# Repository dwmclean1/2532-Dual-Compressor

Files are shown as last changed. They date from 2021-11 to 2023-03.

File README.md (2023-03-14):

# 2532-Dual-Compressor

## What is it?  

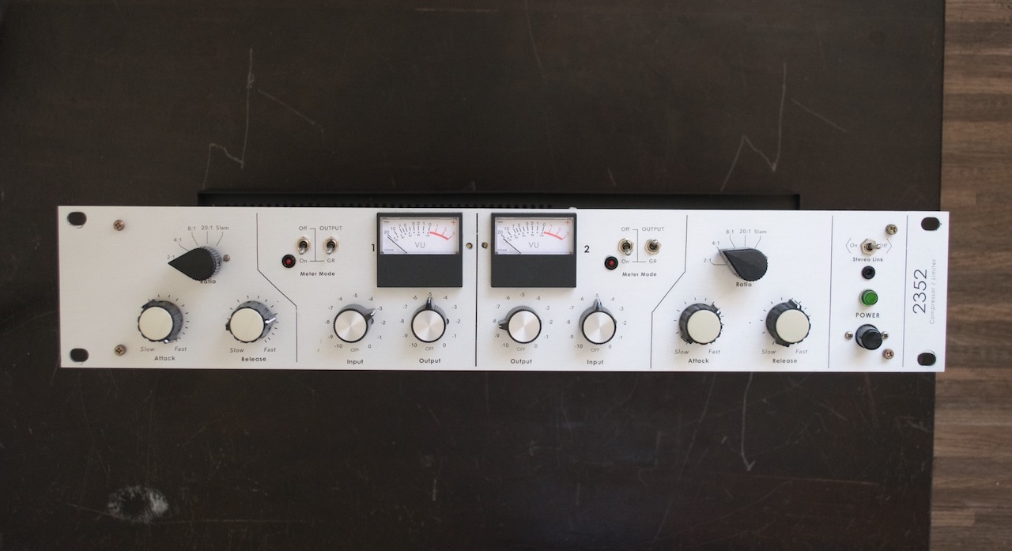
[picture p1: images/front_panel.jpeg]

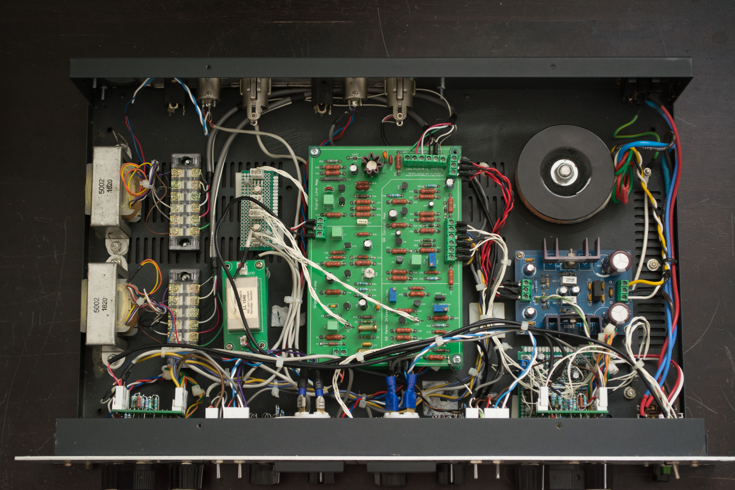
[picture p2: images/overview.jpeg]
  
  
This is a dual mono clone of the Urei 1176LN compressor (2 x 1176 = 2532). The main board is a direct copy of the original unit from the original schematic. The ratio board is taken from the mnats version [seen here](http://mnats.net/1176_revision_d.html).  
  
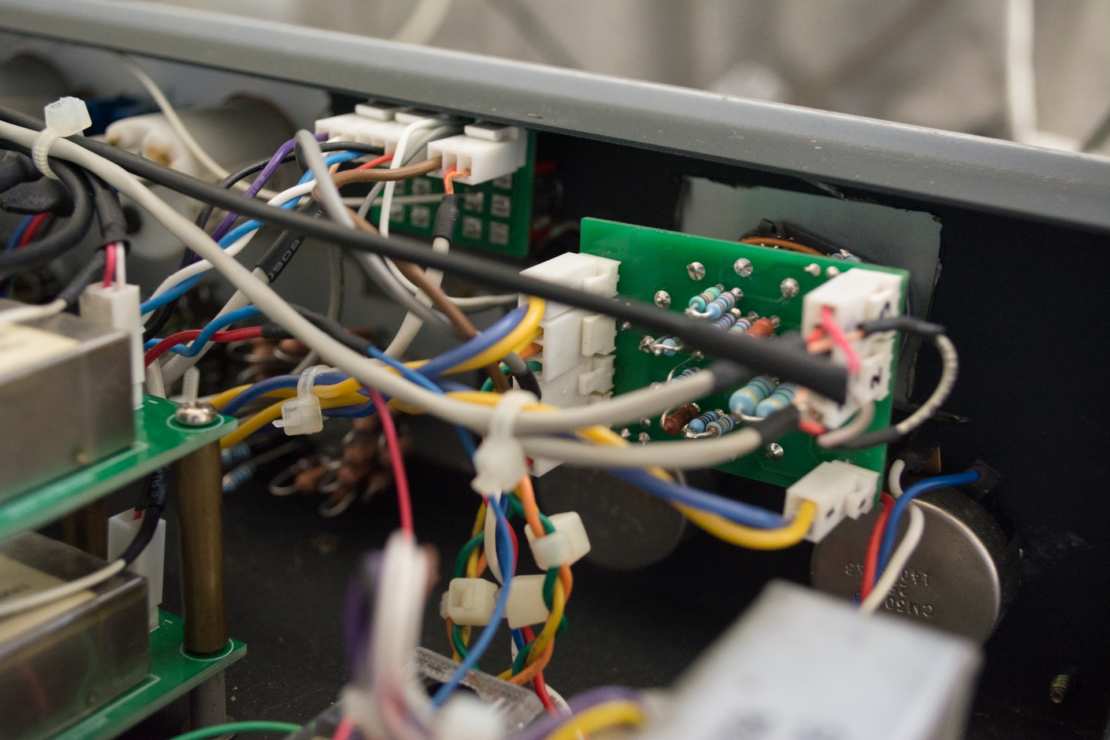
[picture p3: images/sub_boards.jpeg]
  

The meter mode board was designed by me and uses two DPDT toggle switches, one to chose between displaying output level or gain reduction level and one to bypass the compression path. The Stereo Link board is also based on the mnats version which you would usually required two of but to save space and wiring I combined them into one board. All the boards were designed in EagleCAD.  
  
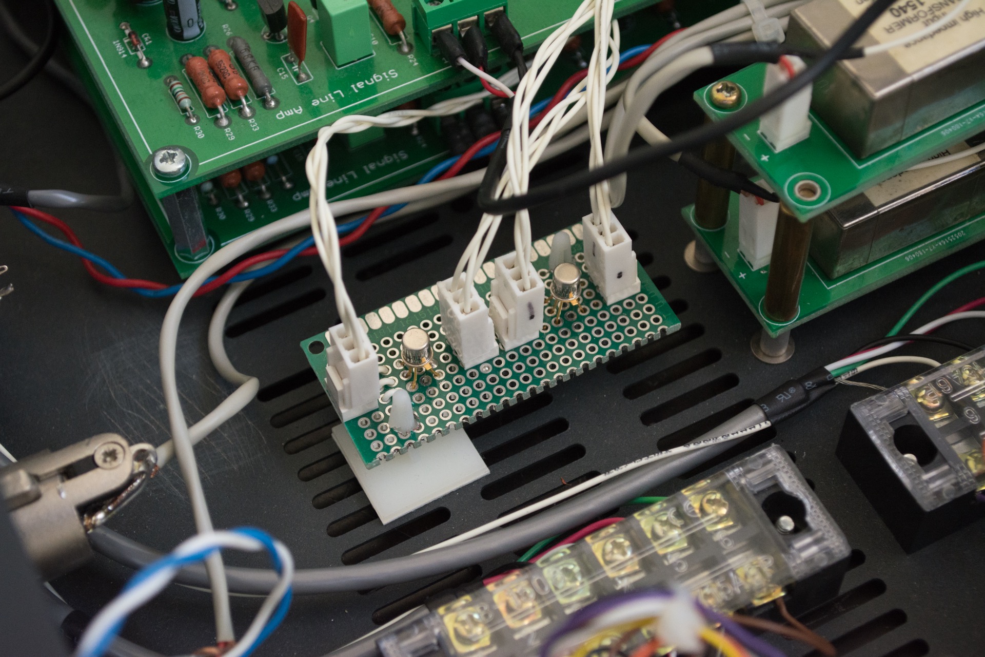
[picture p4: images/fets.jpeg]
  

The original 1176 used two BF245 JFETs, one for the compression path and one for the gain reduction meter. These would need to matched so that the gain reduction shown on the meter is accurate to the actual gain reduction applied to the audio signal. Instead of doing that I decided to use the Interfet INF411 which is a matched pair of JFETs in a simgle package and has similar characteristics to the BF245.

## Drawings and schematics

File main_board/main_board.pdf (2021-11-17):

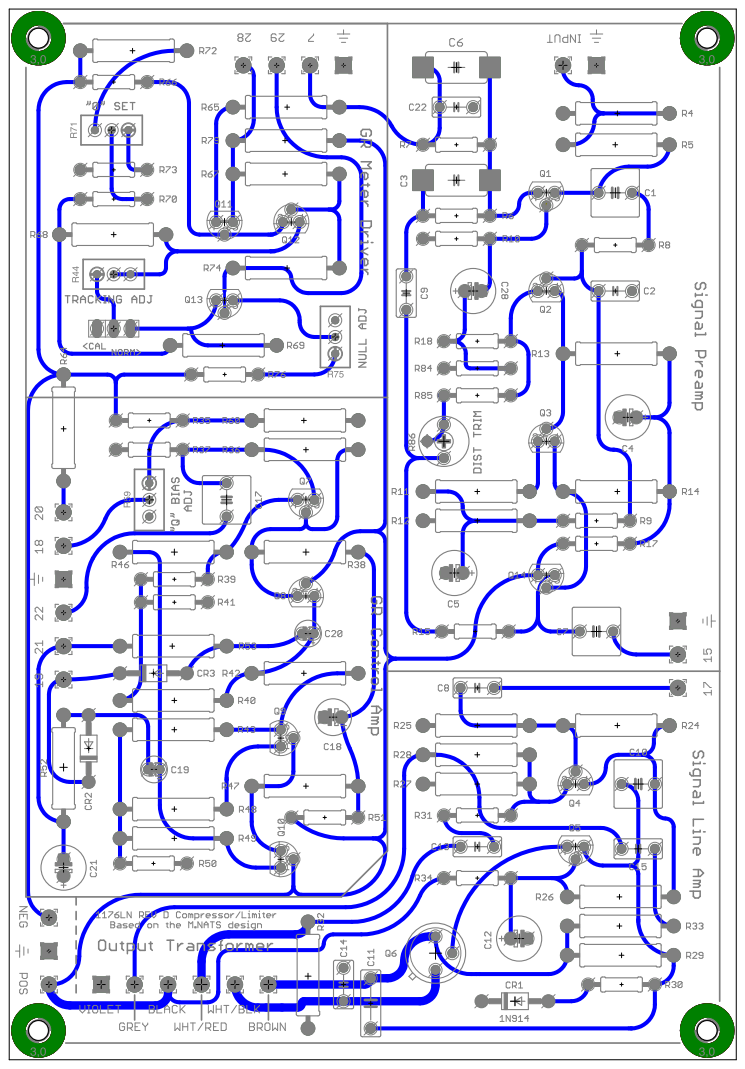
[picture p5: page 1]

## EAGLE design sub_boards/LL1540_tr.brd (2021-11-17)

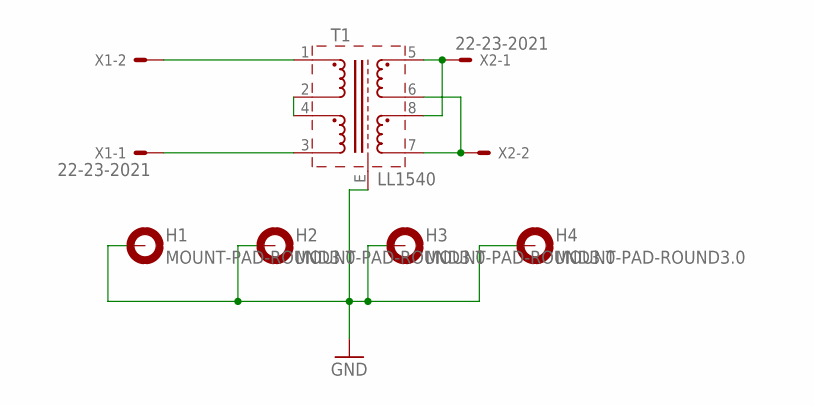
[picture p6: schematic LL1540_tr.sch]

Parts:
H1, H2, H3, H4: MOUNT-PAD-ROUND3.0; 3,0-PAD
T1: LL1540
X1, X2: 22-23-2021

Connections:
GND: H1.B3,0, H2.B3,0, H3.B3,0, H4.B3,0, T1.E
unnamed: T1.2, T1.4
unnamed: T1.1, X1.2
unnamed: T1.3, X1.1
unnamed: T1.5, T1.8, X2.1
unnamed: T1.6, T1.7, X2.2

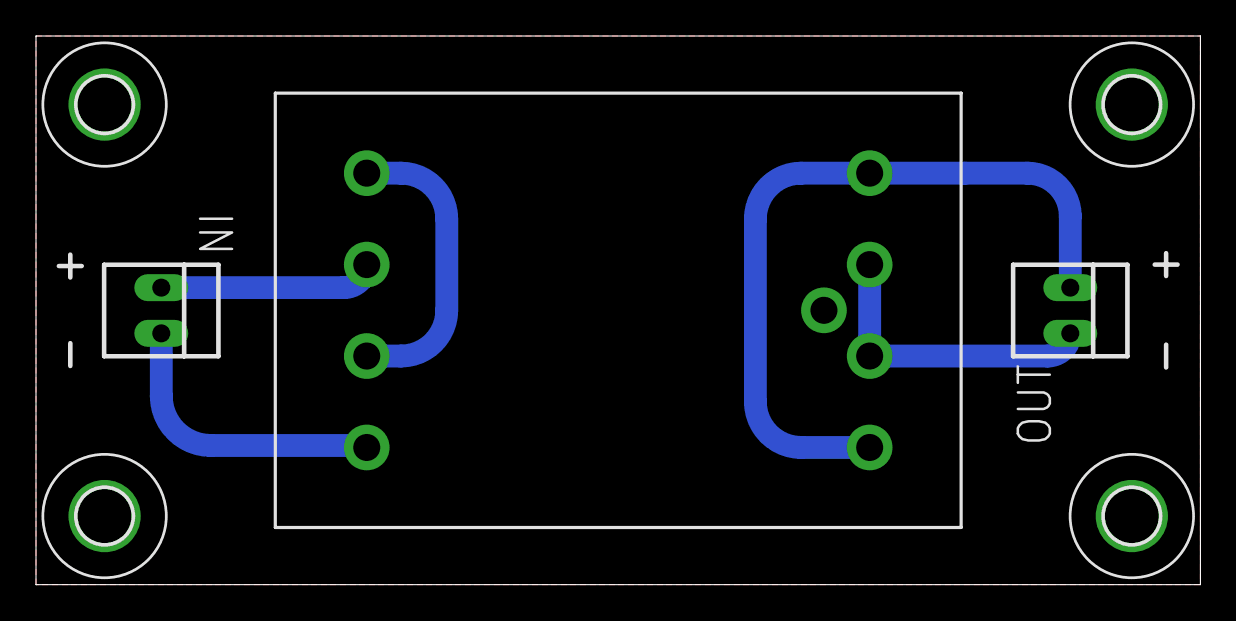
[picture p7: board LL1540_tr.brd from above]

Board: 2 copper layers, 64.7 x 30.5 mm, 7 parts (0 on the bottom side), 6 nets.

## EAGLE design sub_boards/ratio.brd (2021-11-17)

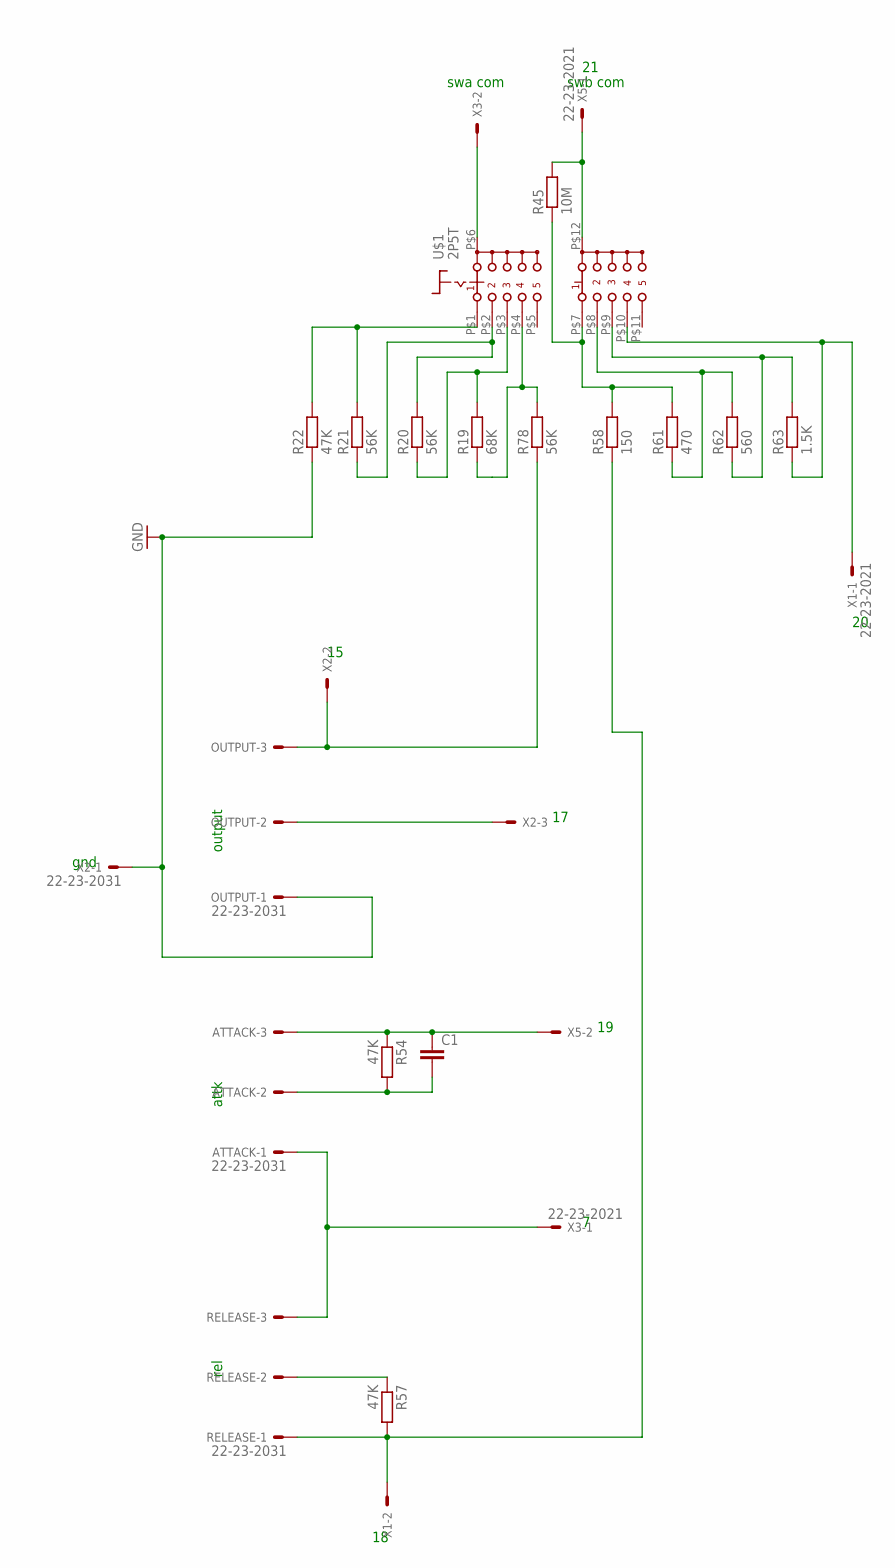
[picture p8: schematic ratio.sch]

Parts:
ATTACK: 22-23-2031
C1: C-EU025-025X050; C025-025X050
OUTPUT: 22-23-2031
R19: 68K; 0204V
R20, R21, R78: 56K; 0204V
R22, R54, R57: 47K; 0204V
R45: 10M; 0204V
R58: 150; 0204V
R61: 470; 0204V
R62: 560; 0204V
R63: 1.5K; 0204V
RELEASE: 22-23-2031
U$1: 2P5T
X1, X3, X5: 22-23-2021
X2: 22-23-2031

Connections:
GND: OUTPUT.1, R22.1, X2.1
unnamed: U$1.P$6 (A), X3.2
unnamed: R45.2, U$1.P$12 (C), X5.1
unnamed: R21.2, R22.2, U$1.P$1 (A1)
unnamed: R20.2, R21.1, U$1.P$2 (A2)
unnamed: R19.2, R20.1, U$1.P$3 (A3)
unnamed: R19.1, R78.2, U$1.P$4 (A4)
unnamed: OUTPUT.3, R78.1, X2.2
unnamed: R45.1, R58.2, R61.2, U$1.P$7 (C1)
unnamed: OUTPUT.2, X2.3
unnamed: ATTACK.3, C1.1, R54.1, X5.2
unnamed: R61.1, R62.2, U$1.P$8 (C2)
unnamed: R62.1, R63.2, U$1.P$9 (C3)
unnamed: R63.1, U$1.P$10 (C4), X1.1
unnamed: ATTACK.2, C1.2, R54.2
unnamed: ATTACK.1, RELEASE.3, X3.1
unnamed: R57.1, RELEASE.2
unnamed: R57.2, R58.1, RELEASE.1, X1.2

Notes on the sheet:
swa com
swb com
gnd
attk
rel
output

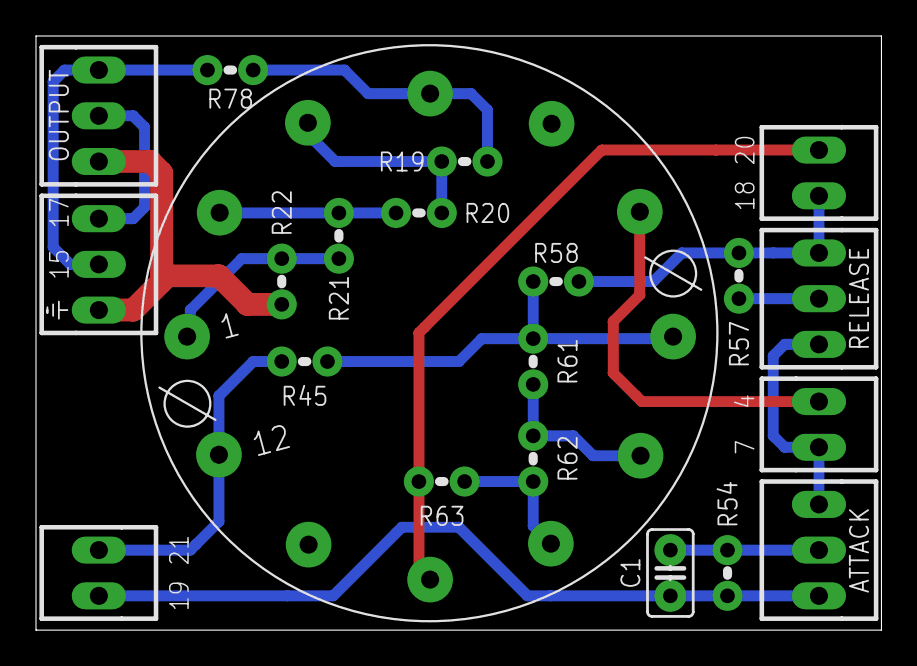
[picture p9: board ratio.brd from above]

Board: 2 copper layers, 47.0 x 33.0 mm, 21 parts (0 on the bottom side), 18 nets.

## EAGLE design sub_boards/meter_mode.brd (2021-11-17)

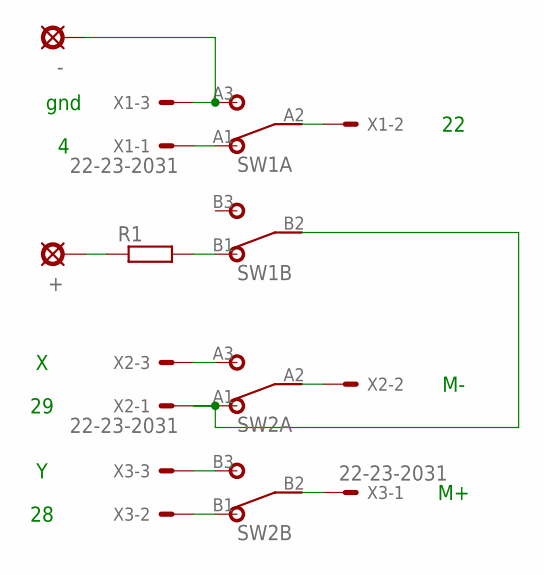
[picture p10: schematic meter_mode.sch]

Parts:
+: PADO; ROUND
-: PAD; SQUARE
R1: R-EU_0204/2V; 0204V
SW1, SW2: DPDT
X1, X2, X3: 22-23-2031

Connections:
unnamed: SW2.A3 (3), X2.3
unnamed: SW1.B2 (2), SW2.A1 (1), X2.1
unnamed: SW1.A1 (1), X1.1
unnamed: SW2.B3 (3), X3.3
unnamed: SW2.B1 (1), X3.2
unnamed: SW2.B2 (2), X3.1
unnamed: SW2.A2 (2), X2.2
unnamed: SW1.A2 (2), X1.2
unnamed: R1.2, SW1.B1 (1)
unnamed: -.1, SW1.A3 (3), X1.3
unnamed: +.1, R1.1

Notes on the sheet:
gnd

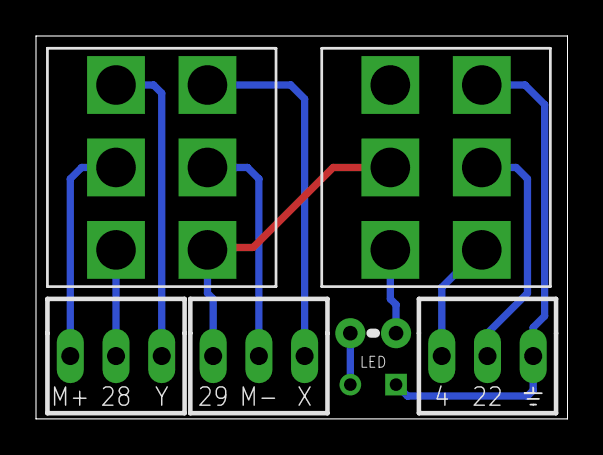
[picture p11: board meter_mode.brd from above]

Board: 2 copper layers, 29.5 x 21.3 mm, 8 parts (0 on the bottom side), 11 nets.

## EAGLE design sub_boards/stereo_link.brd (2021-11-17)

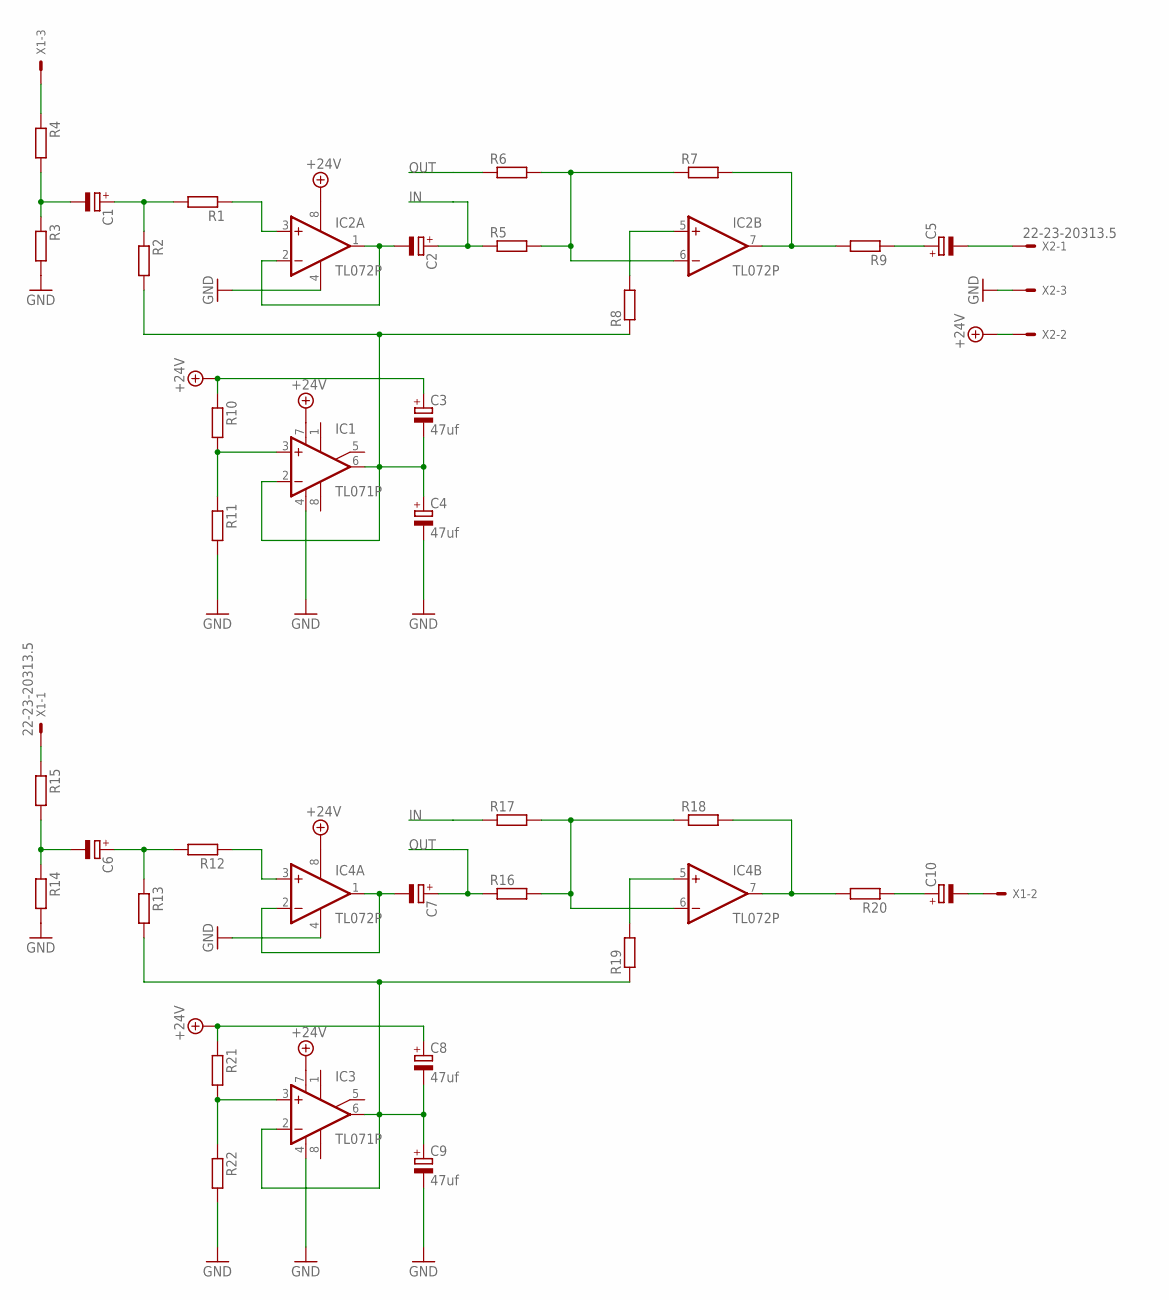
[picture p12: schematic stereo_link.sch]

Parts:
C1, C2, C5, C6, C7, C10: CPOL-EUE1.8-4; E1,8-4
C3, C4, C8, C9: 47uf; E2,5-6E
IC1, IC3: TL071P; DIL08
IC2, IC4: TL072P; DIL08
R1, R2, R3, R4, R5, R6, R7, R8, R9, R10, R11, R12, R13, R14, R15, R16, R17, R18, R19, R20, R21, R22: R-EU_0204/7; 0204/7
X1, X2: 22-23-20313.5; 3.5MM

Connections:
+24V: C3.+, C8.+, IC1.7 (V+), IC2.8 (V+), IC3.7 (V+), IC4.8 (V+), R10.1, R21.1, X2.P$2
GND: C4.-, C9.-, IC1.4 (V-), IC2.4 (V-), IC3.4 (V-), IC4.4 (V-), R3.2, R11.2, R14.2, R22.2, X2.P$3
unnamed: C1.-, R3.1, R4.2
unnamed: C1.+, R1.2, R2.1
unnamed: C6.-, R14.1, R15.2
unnamed: IC2.3 (+IN), R1.1
unnamed: C2.-, IC2.1 (OUT), IC2.2 (-IN)
unnamed: R15.1, X1.P$1
unnamed: C7.+, R6.1, R16.1
unnamed: IC2.6 (-IN), R5.2, R6.2, R7.1
unnamed: IC2.5 (+IN), R8.2
unnamed: IC2.7 (OUT), R7.2, R9.2
unnamed: C5.+, R9.1
unnamed: C5.-, X2.P$1
unnamed: IC1.3 (+IN), R10.2, R11.1
unnamed: C10.-, X1.P$2
unnamed: C6.+, R12.2, R13.1
unnamed: IC4.3 (+IN), R12.1
unnamed: C3.-, C4.+, IC1.2 (-IN), IC1.6 (OUT), R2.2, R8.1
unnamed: C7.-, IC4.1 (OUT), IC4.2 (-IN)
unnamed: R4.1, X1.P$3
unnamed: C2.+, R5.1, R17.1
unnamed: IC4.6 (-IN), R16.2, R17.2, R18.1
unnamed: IC4.5 (+IN), R19.2
unnamed: IC4.7 (OUT), R18.2, R20.2
unnamed: C10.+, R20.1
unnamed: IC3.3 (+IN), R21.2, R22.1
unnamed: C8.-, C9.+, IC3.2 (-IN), IC3.6 (OUT), R13.2, R19.1

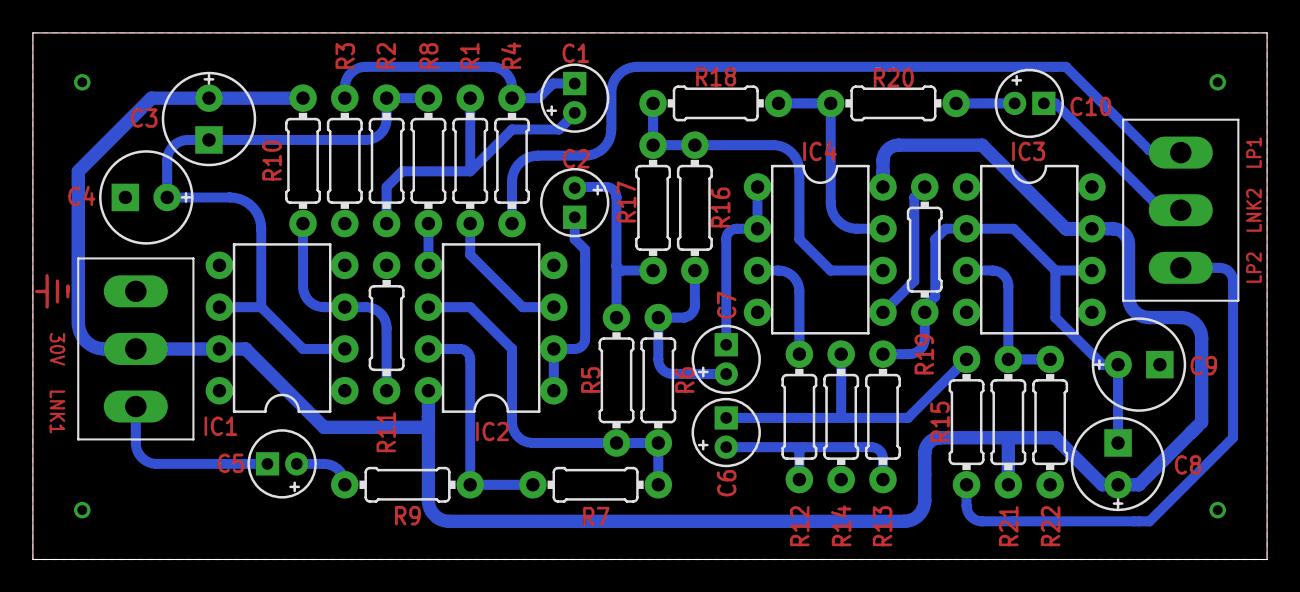
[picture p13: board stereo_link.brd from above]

Board: 2 copper layers, 75.0 x 32.0 mm, 38 parts (0 on the bottom side), 28 nets.

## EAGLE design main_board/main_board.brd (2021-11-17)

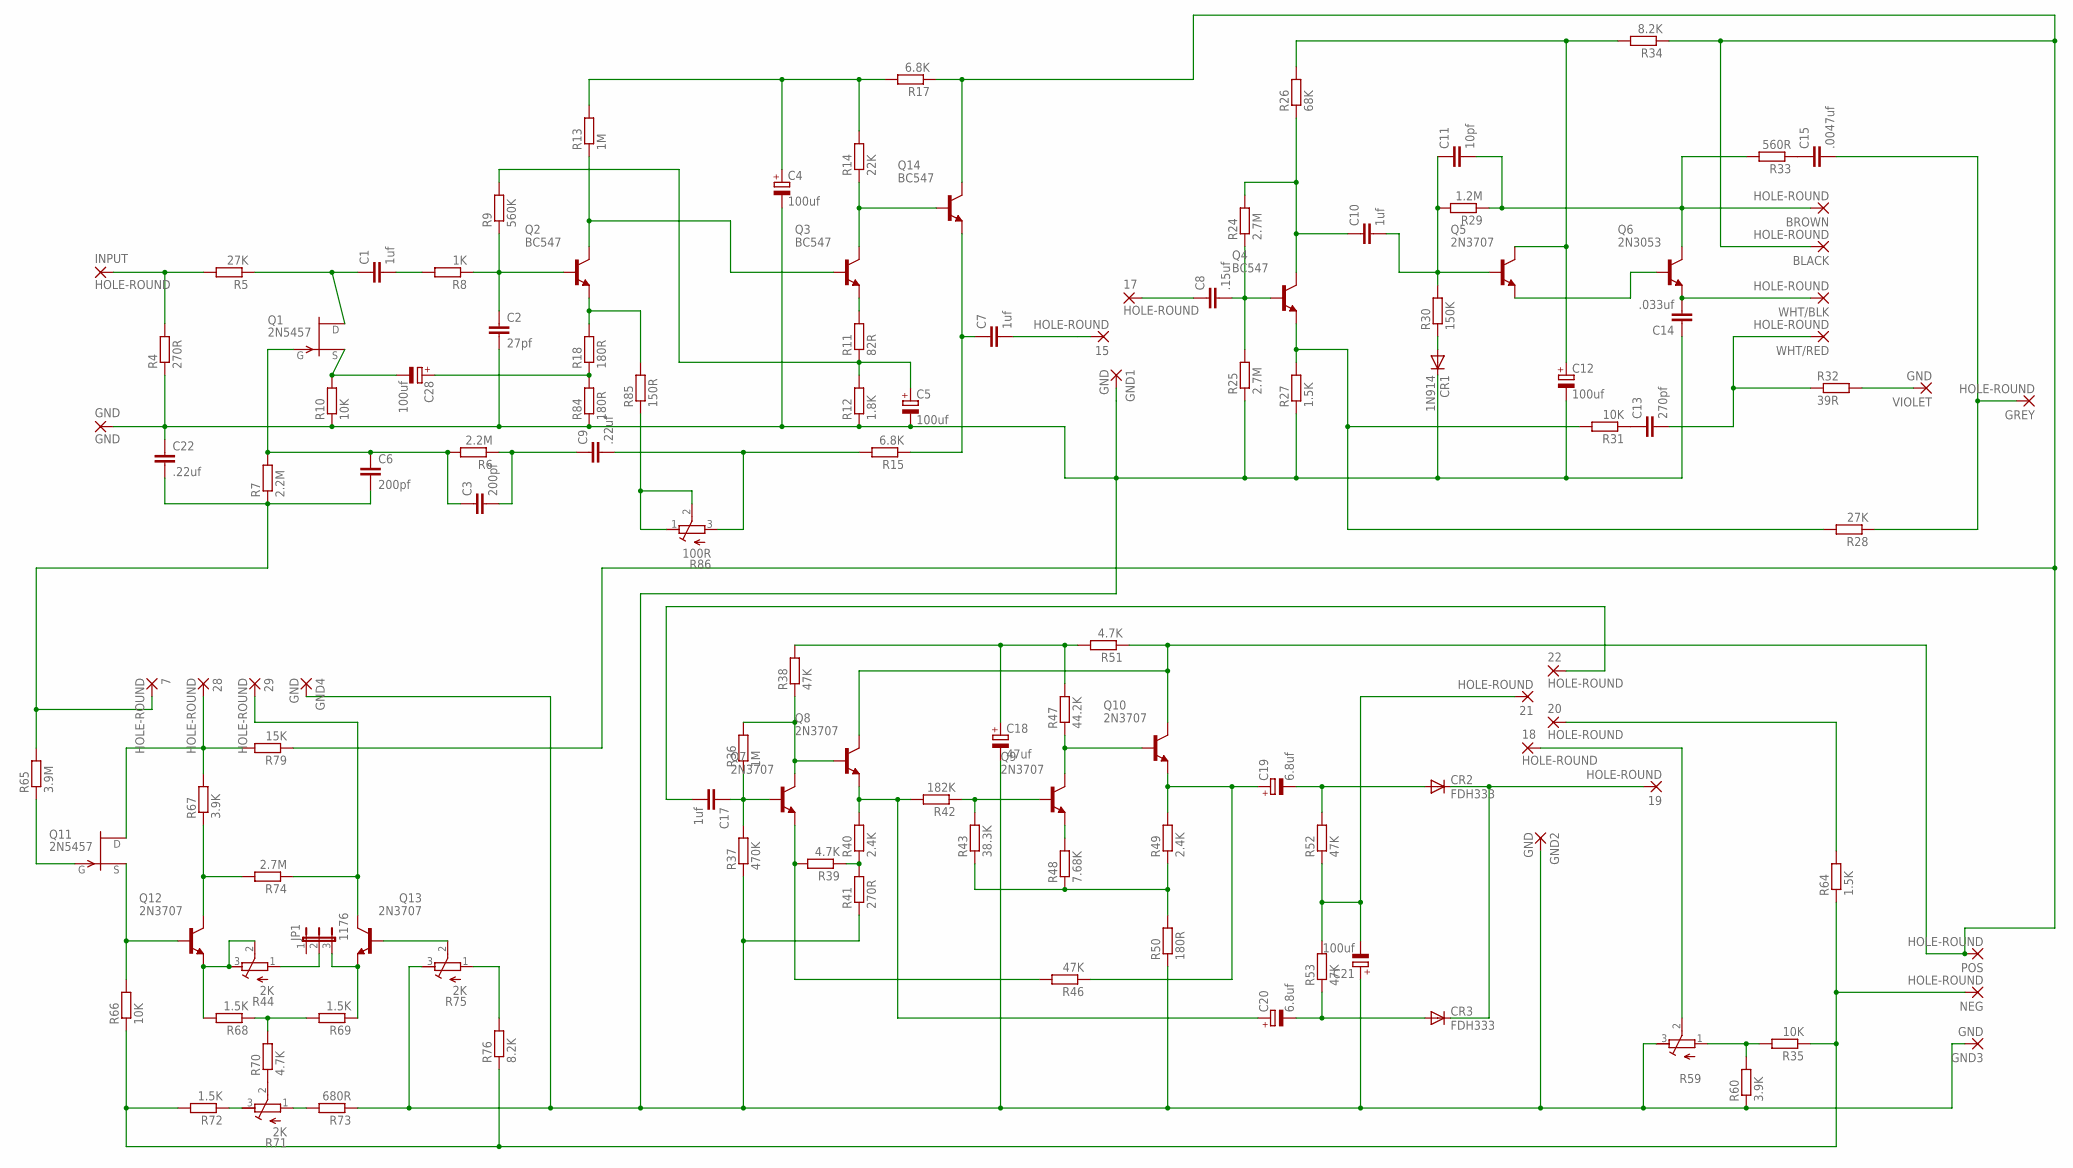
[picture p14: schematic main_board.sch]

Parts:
7, 15, 17, 18, 19, 20, 21, 22, 28, 29: HOLE-ROUND
BLACK: HOLE-ROUND
BROWN: HOLE-ROUND
C1, C7, C10, C17: 1uf; SQUARE
C2: 27pf; C-EU-ROUND
C3, C6: 200pf; C050-024X044
C4, C5, C12, C21, C28: 100uf; ROUND7
C8: .15uf; C-EU-ROUND
C9, C22: .22uf; C-EU-ROUND
C11: 10pf; C075-032X103
C13: 270pf; C-EU-ROUND
C14: .033uf; C-EU-ROUND
C15: .0047uf; C-EU-ROUND
C18: 47uf; E2,5-6
C19, C20: 6.8uf; E1,8-4
CR1: 1N914; DO41-10
CR2, CR3: FDH333; DO41-10
GND, GND1, GND2, GND3, GND4: GND; HOLE-SQUARE
GREY: HOLE-ROUND
INPUT: HOLE-ROUND
JP1: 1176
NEG: HOLE-ROUND
POS: HOLE-ROUND
Q1, Q11: 2N5457; TO92
Q2, Q3, Q4, Q14: BC547; TO92
Q5, Q7, Q8, Q9, Q10, Q12, Q13: 2N3707; TO92
Q6: 2N3053; TO39
R4: 270R; ROUND
R5, R28: 27K; ROUND
R6, R7: 2.2M; 0207/10
R8: 1K; 0207/10
R9: 560K; 0207/10
R10, R31, R35, R66: 10K; 0207/10
R11: 82R; ROUND
R12: 1.8K; ROUND
R13, R36: 1M; ROUND
R14: 22K; ROUND
R15, R17: 6.8K; 0207/10
R18, R50, R84: 180R; 0207/10
R24, R25, R74: 2.7M; ROUND
R26: 68K; ROUND
R27, R64, R68, R69, R72: 1.5K; ROUND
R29: 1.2M; ROUND
R30: 150K; 0207/10
R32: 39R; ROUND
R33: 560R; ROUND
R34, R76: 8.2K; 0207/10
R37: 470K; 0207/10
R38, R46, R52, R53: 47K; ROUND
R39, R51, R70: 4.7K; 0207/10
R40, R49: 2.4K; ROUND
R41: 270R; 0207/10
R42: 182K; ROUND
R43: 38.3K; ROUND
R44, R71, R75: 2K; RTRIM3296W
R47: 44.2K; ROUND
R48: 7.68K; ROUND
R59: R-TRIMM3296W; RTRIM3296W
R60, R67: 3.9K; ROUND
R65: 3.9M; ROUND
R73: 680R; 0207/10
R79: 15K; ROUND
R85: 150R; 0207/10
R86: 100R; RTRIM3339P
VIOLET: GND; HOLE-SQUARE
WHT/BLK: HOLE-ROUND
WHT/RED: HOLE-ROUND

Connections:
GND: C2.2, C4.-, C5.-, C12.-, C14.1, C18.-, C21.+, C22.1, CR1.C, GND.1, GND1.1, GND2.1, GND3.1, GND4.1, R4.P$1 (1), R10.1, R12.P$1 (1), R25.P$1 (1), R27.P$1 (1), R37.1, R41.1, R50.1, R59.3 (E), R60.P$1 (1), R73.1, R75.3 (E), R84.1
unnamed: 22.1, C17.2
unnamed: Q11.1 (G), R65.P$1 (1)
unnamed: 28.1, Q11.3 (D), R67.P$3 (2), R79.P$3 (2)
unnamed: Q11.2 (S), Q12.3 (B), R66.2
unnamed: NEG.1, R35.1, R64.P$1 (1), R66.1, R72.P$3 (2), R76.1
unnamed: R70.1, R71.2 (S)
unnamed: Q12.2 (C), R67.P$1 (1), R74.P$3 (2)
unnamed: R68.P$1 (1), R69.P$3 (2), R70.2
unnamed: Q12.1 (E), R44.2 (S), R44.3 (E), R68.P$3 (2)
unnamed: 20.1, R64.P$3 (2)
unnamed: JP1.3, Q13.1 (E), R69.P$1 (1)
unnamed: 29.1, Q13.2 (C), R74.P$1 (1)
unnamed: R71.3 (E), R72.P$1 (1)
unnamed: Q13.3 (B), R75.2 (S)
unnamed: Q3.1 (C), Q14.2 (B), R14.P$1 (1)
unnamed: R75.1 (A), R76.2
unnamed: INPUT.1, R4.P$3 (2), R5.P$3 (2)
unnamed: JP1.2, R44.1 (A)
unnamed: Q4.3 (E), R27.P$3 (2), R28.P$3 (2), R31.2
unnamed: R71.1 (A), R73.2
unnamed: C1.1, Q1.3 (D), R5.P$1 (1)
unnamed: C1.2, R8.2
unnamed: C3.1, C6.1, Q1.1 (G), R6.2, R7.2
unnamed: C28.-, Q1.2 (S), R10.2
unnamed: C13.2, R32.P$1 (1), WHT/RED.1
unnamed: C3.2, C9.1, R6.1
unnamed: C28.+, R18.1, R84.2
unnamed: 15.1, C7.2
unnamed: C2.1, Q2.2 (B), R8.1, R9.1
unnamed: C17.1, Q7.3 (B), R36.P$1 (1), R37.2
unnamed: Q2.3 (E), R18.2, R85.2
unnamed: C9.2, R15.2, R86.3 (A)
unnamed: R85.1, R86.1 (E), R86.2 (S)
unnamed: Q2.1 (C), Q3.2 (B), R13.P$1 (1)
unnamed: C5.+, R9.2, R11.P$1 (1), R12.P$3 (2)
unnamed: C4.+, R13.P$3 (2), R14.P$3 (2), R17.2
unnamed: Q5.1 (E), Q6.2 (B)
unnamed: Q3.3 (E), R11.P$3 (2)
unnamed: BROWN.1, C11.2, Q6.3 (C), R29.P$1 (1), R33.P$3 (2)
unnamed: C7.1, Q14.3 (E), R15.1
unnamed: R35.2, R59.1 (A), R60.P$3 (2)
unnamed: C15.2, GREY.1, R28.P$1 (1)
unnamed: Q7.2 (C), Q8.3 (B), R36.P$3 (2), R38.P$1 (1)
unnamed: 17.1, C8.1
unnamed: C8.2, Q4.2 (B), R24.P$1 (1), R25.P$3 (2)
unnamed: Q7.1 (E), R39.2, R46.P$3 (2)
unnamed: C10.1, Q4.1 (C), R24.P$3 (2), R26.P$1 (1)
unnamed: R39.1, R40.P$1 (1), R41.2
unnamed: C10.2, C11.1, Q5.3 (B), R29.P$3 (2), R30.2
unnamed: C20.-, CR3.A, R53.P$1 (1)
unnamed: CR1.A, R30.1
unnamed: C18.+, R38.P$3 (2), R47.P$3 (2), R51.2
unnamed: C12.+, Q5.2 (C), R26.P$3 (2), R34.2
unnamed: C13.1, R31.1
unnamed: C20.+, Q8.1 (E), R40.P$3 (2), R42.P$3 (2)
unnamed: BLACK.1, POS.1, Q8.2 (C), Q10.2 (C), Q14.1 (C), R17.1, R34.1, R51.1, R79.P$1 (1)
unnamed: Q9.3 (B), R42.P$1 (1), R43.P$3 (2)
unnamed: C15.1, R33.P$1 (1)
unnamed: R43.P$1 (1), R48.P$1 (1), R49.P$1 (1), R50.2
unnamed: Q9.1 (E), R48.P$3 (2)
unnamed: Q9.2 (C), Q10.3 (B), R47.P$1 (1)
unnamed: 19.1, CR2.C, CR3.C
unnamed: R32.P$3 (2), VIOLET.1
unnamed: C19.+, Q10.1 (E), R46.P$1 (1), R49.P$3 (2)
unnamed: 21.1, C21.-, R52.P$1 (1), R53.P$3 (2)
unnamed: 7.1, C6.2, C22.2, R7.1, R65.P$3 (2)
unnamed: C19.-, CR2.A, R52.P$3 (2)
unnamed: 18.1, R59.2 (S)
Q6: C14.2, Q6.1 (E), WHT/BLK.1

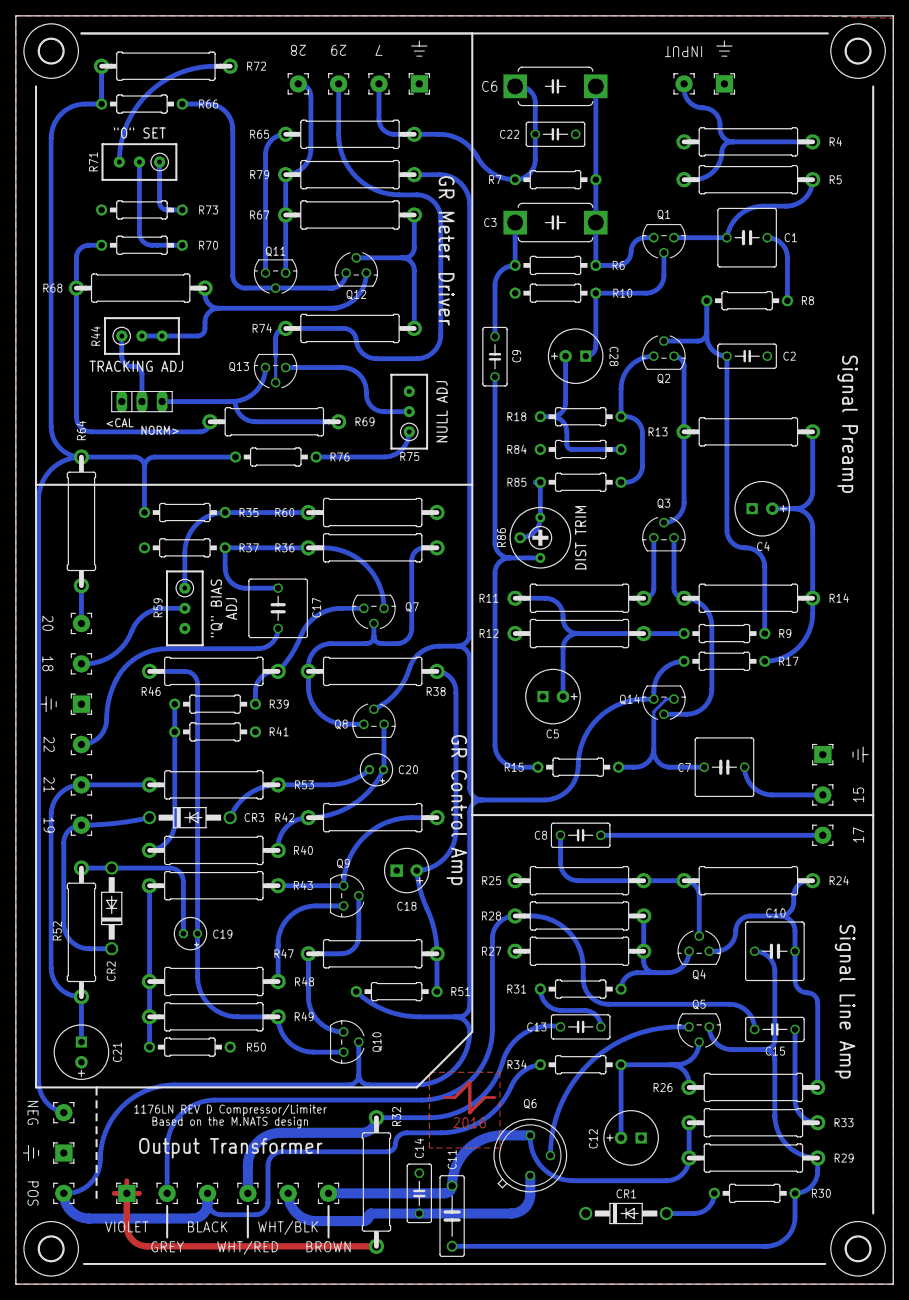
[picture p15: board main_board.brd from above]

Board: 2 copper layers, 110.5 x 159.7 mm, 130 parts (0 on the bottom side), 70 nets.

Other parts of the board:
U$1, U$2, U$3, U$4: 3,0

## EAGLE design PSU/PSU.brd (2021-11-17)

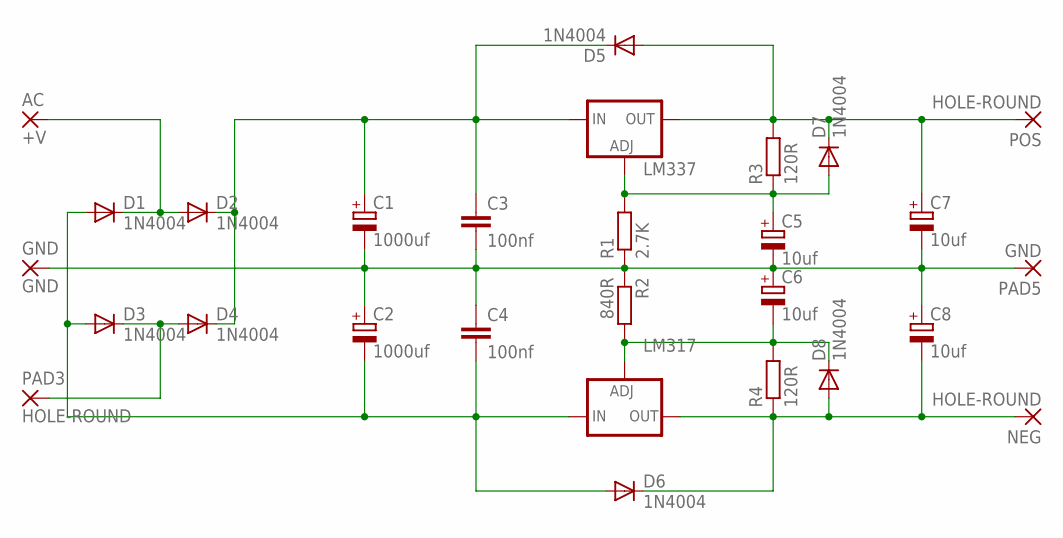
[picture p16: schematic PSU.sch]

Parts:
AC: +V; HOLE-ROUND
C1, C2: 1000uf; E3,5-10
C3, C4: 100nf; C025-025X050
C5, C6, C7, C8: 10uf; E2,5-5
D1, D2, D3, D4, D5, D6, D7, D8: 1N4004; DO41-10
GND: GND; HOLE-SQUARE
LM317: LM337TS; 337TS
LM337: LM317TS; 317TS
NEG: HOLE-ROUND
PAD3: HOLE-ROUND
PAD5: GND; HOLE-SQUARE
POS: HOLE-ROUND
R1: 2.7K; 0204/7
R2: 840R; 0204/7
R3, R4: 120R; 0204/7

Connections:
GND: C1.-, C2.+, C3.2, C4.1, C5.-, C6.+, C7.-, C8.+, GND.1, PAD5.1, R1.1, R2.1
unnamed: AC.1, D1.C, D2.A
unnamed: D3.C, D4.A, PAD3.1
unnamed: C6.-, D8.C, LM317.1 (ADJ), R2.2, R4.2
unnamed: C5.+, D7.A, LM337.1 (ADJ), R1.2, R3.1
unnamed: C8.-, D6.C, D8.A, LM317.3 (OUT), NEG.1, R4.1
unnamed: C1.+, C3.1, D2.C, D4.C, D5.C, LM337.3 (IN)
unnamed: C7.+, D5.A, D7.C, LM337.2 (OUT), POS.1, R3.2
unnamed: C2.-, C4.2, D1.A, D3.A, D6.A, LM317.2 (IN)

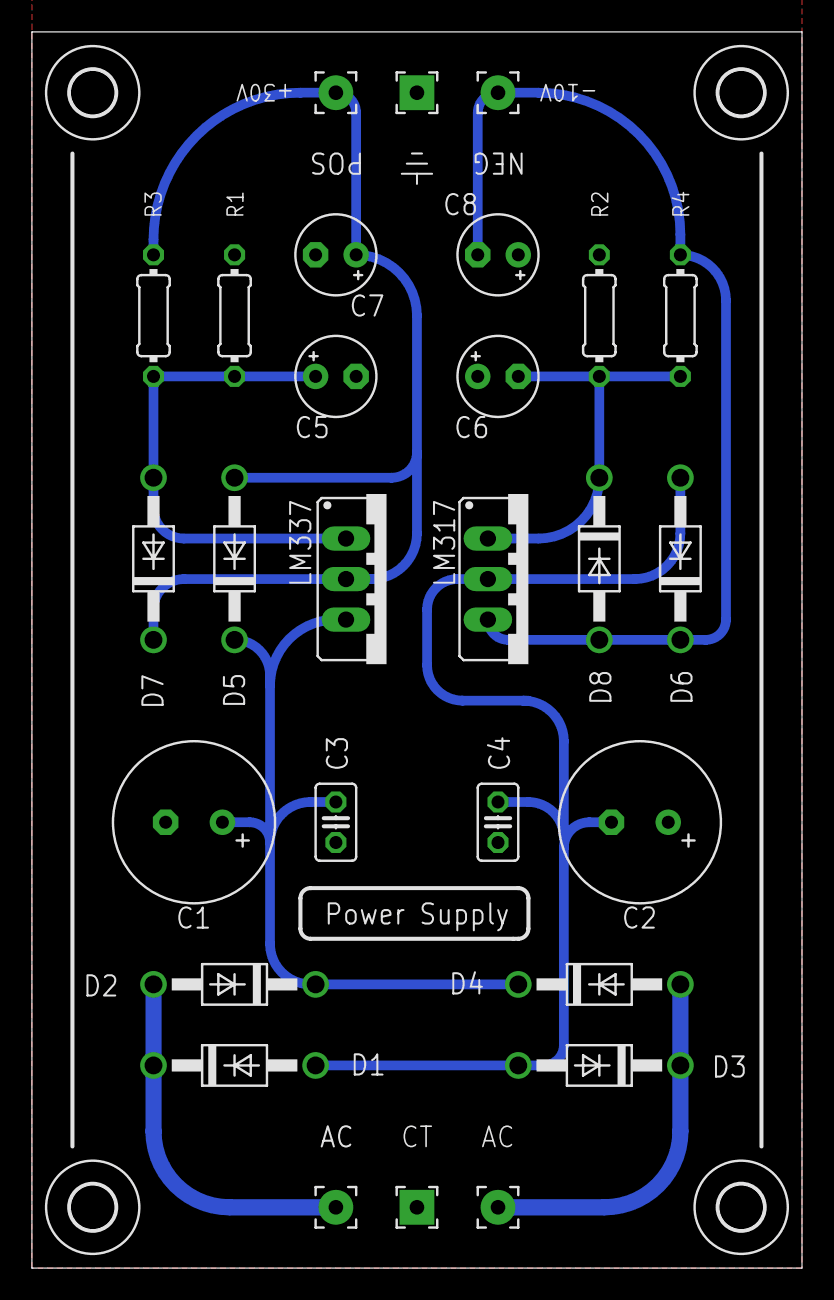
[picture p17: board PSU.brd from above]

Board: 2 copper layers, 48.3 x 77.5 mm, 32 parts (0 on the bottom side), 9 nets.

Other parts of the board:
U$1, U$2, U$3, U$4: 2,8
